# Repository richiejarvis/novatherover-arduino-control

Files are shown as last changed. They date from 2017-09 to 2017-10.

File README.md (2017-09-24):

# novatherover-arduino-control
Arduino Control code for Nova the Rover

*Richie Jarvis - http://nebul.ae*
*2017-09-24 - GPL licenced*

## Introduction
Nova the Rover (https://www.facebook.com/novatherover) is an Arduino controlled project I started a couple of years ago with a simple 24v Mobility Scooter brought off Ebay.  

## 2016 - Initial Chassis Building

I started off by rebuilding the chassis.  In hindsight I made more work for myself, but did learn to weld of-sorts.  In the first year of operation the contraption was a powered pull-cart/human carrying workhorse.  The steering was backwards at her first public outing, which made control interesting.  She was present at Lewes Bonfire Celebrations in 2016 lurking with the Bonfire Boyes, and got covered in red paper from firecrackers.

It was always my hope to convert the chassis into a remotely steerable unit, so I purchased a Lynxmotion PS2 controller (http://www.robotshop.com/uk/lynxmotion-ps2-controller-v4.html) and a cheap 12v 30mm/s Linear Actuator from Ebay (http://www.ebay.co.uk/itm/222620724976).

## 2017 - Conversion to Remote Control via PS2 Controller

Originally I was hoping to use the original computer/controller unit that came with the Mobility scooter.  Unfortunately, that was not as easy as I first hoped, so I ditched that idea and purchased a 30A Cytron DC Motor Driver (http://www.robotshop.com/en/cytron-30a-5-30v-single-brushed-dc-motor-driver.html) to control the motors.

I then added an Arduino Uno (http://www.robotshop.com/uk/arduino-uno-r3-usb-microcontroller.html) and a 4 relay board to handle the switching of polarity, turning the magnetic brake on/off, etc to finish things off.

This project is the current set of control code as it develops over time.

##Thinking Ahead

Thoughts/Plans so far:
1. Replace on/off relay control on Linear Actuator with a proper ESC to give more granular steering.
2. Add navigation lights, (loud) horn and control indicator LED to signal status
3. Add Distance sensor(s)
4. Add magnetic detector
5. Add camera
6. Add Raspberry Pi + intelligence(!?)
7. Add weaponry :)

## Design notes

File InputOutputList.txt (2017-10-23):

Battery1+/24vPositive/12vPositive
Battery1-/12vGround
Battery2+
Battery2-/24vGround
24vBrake
24vBrake
24vMotor
24vMotor

12vSteering
12vSteering
24vGround
24vLights1
24vLights2
24vLights3
12vGround
12vMischief1
12vMischief2
12vMischief3
12vMischief4
12vMischief5

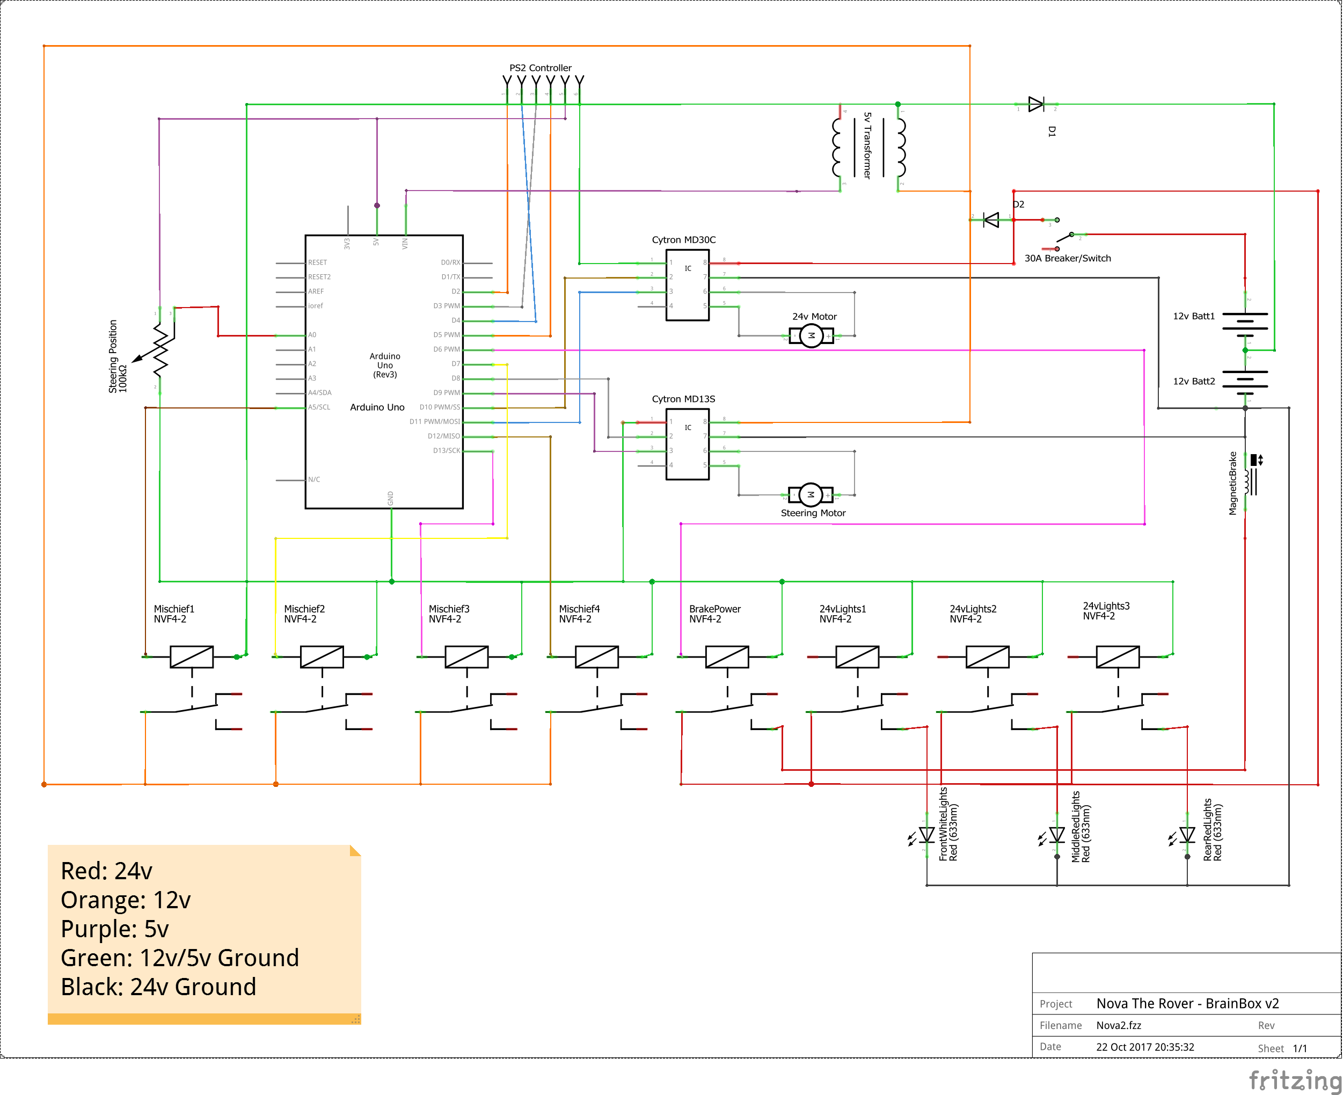
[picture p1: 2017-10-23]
Nova2_schem.png

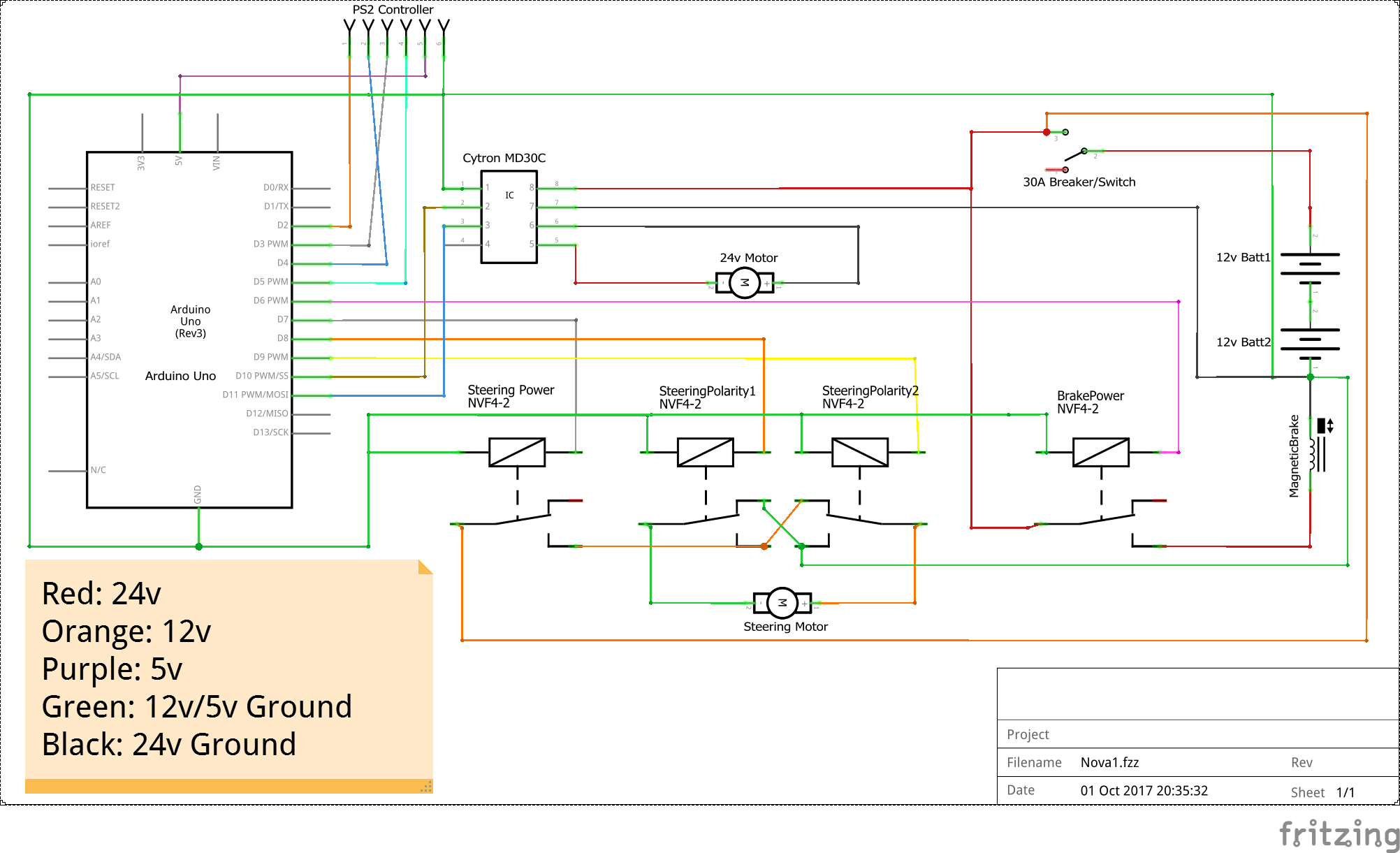
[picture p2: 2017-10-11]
Nova1_schem.png

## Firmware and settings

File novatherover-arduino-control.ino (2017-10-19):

#include <PS2X_lib.h>

// PS2 Controller pins
#define PS2_DAT        2
#define PS2_CMD        4
#define PS2_ATT        3
#define PS2_CLK        5

// Magnetic Brake
#define RELAY1_PIN     6

// Steering Power
#define RELAY2_PIN     7

// Steering Relay pins
#define RELAY3_PIN     8
#define RELAY4_PIN     9

// Motor direction pin
#define DIR_PIN        10

// Throttle pin
#define PWM_PIN        11

#define PS2_PRESSURES  false
#define PS2_RUMBLE     false

PS2X ps2x; // create PS2 Controller Class

// Initial Startup Variables
int error = 0;
byte type = 0;
byte vibrate = 0;
int pwm_value = 0;
int throttle_pos = 127;
int steering_pos = 127;

int max_speed = 20;
int counter = 0;
int buttonBounceCounter = 0;

// Set pin vars to off/high
int motor_direction = HIGH;
int brake_power = true;
int steering_power = HIGH;
int steering_relay_1 = HIGH;
int steering_relay_2 = HIGH;
int increment = 0;
int target_speed = 0;
int pss_lx = 0;
int pss_ly = 0;
int pss_rx = 0;
int pss_ry = 0;
int lights_counter = 0;
int light_delay = 40;

boolean cruise_control = false;
boolean beast_mode = false;
boolean first_run = false;
boolean skip_initial = true;
boolean controller_present = false;
boolean accept_change = true;


// Storage array to record previous condition
int storage_array[20];

// Card reset function
void(* resetFunc) (void) = 0;


void flashLights(int max_count) {
  // Flash Lights to indicate readyness
  for (int count = 0 ; count < max_count  ; count++) {
    digitalWrite(RELAY1_PIN, brake_power);
    delay(light_delay);
    digitalWrite(RELAY1_PIN, !brake_power);
    delay(light_delay);
  }
  digitalWrite(RELAY1_PIN, brake_power);
}


void setup()
{
  Serial.begin(57600);
  delay(300);
  // GamePad(clock, command, attention, data, Pressures?, Rumble?) check for error
  error = ps2x.config_gamepad(PS2_CLK, PS2_CMD, PS2_ATT, PS2_DAT, PS2_PRESSURES, PS2_RUMBLE);

  if (error == 1)
    Serial.println("No controller found, check wiring, see readme.txt to enable debug. visit www.billporter.info for troubleshooting tips");

  else if (error == 2)
    Serial.println("Controller found but not accepting commands. see readme.txt to enable debug. Visit www.billporter.info for troubleshooting tips");

  else if (error == 3)
    Serial.println("Controller refusing to enter Pressures mode, may not support it. ");

  // Something up with the controller - abort and reboot!
  // Delay in place to stop it checking too frequently....
  if (error != 0) {
    Serial.println("Init Restart");
    delay(2000);
    resetFunc();
  } else {
    Serial.println("Startup Successful");
    controller_present = true;
  }

  // Set pin 11 PWM frequency to 62500 Hz (62500/1 = 62500)
  TCCR2B = TCCR2B & 0b11111000 | 0x01;

  //Initialise outputs
  pinMode(PWM_PIN, OUTPUT);
  pinMode(DIR_PIN, OUTPUT);
  pinMode(RELAY1_PIN, OUTPUT);
  pinMode(RELAY2_PIN, OUTPUT);
  pinMode(RELAY3_PIN, OUTPUT);
  pinMode(RELAY4_PIN, OUTPUT);
  // Set initial states
  digitalWrite(RELAY1_PIN, brake_power);
  digitalWrite(RELAY2_PIN, steering_power);
  digitalWrite(RELAY3_PIN, steering_relay_1);
  digitalWrite(RELAY4_PIN, steering_relay_2);


}

// Controls
// PSAB_L1 - Max Speed Down
// PSAB_R1 - Max Speed Up
// PSAB_CIRCLE - Cruise On/Off
// PSS_LY/PSS_RY - Left Stick (Up/Down) - Throttle
// PSS_LX/PSS_RX - Right Stick (Left/Right) - Steering
// PSB_TRIANGLE - Speed 20 (Lowest working speed)
// PSB_SQUARE - Emergency Stop

void speedChange() {
  first_run = true;
  Serial.print("SC");
  // Check for beast_mode first....
  if (!beast_mode) {
    if ((target_speed != pwm_value)) {
      // Speed up more gently

      if (first_run) {
        // Only set the increment once
        increment = target_speed / 50;
        if (increment < 1) {
          increment = 1;
        }
        first_run = false;
      }
      if (target_speed > pwm_value) {
        pwm_value = pwm_value + increment;
        if (pwm_value > target_speed) {
          pwm_value = target_speed;
        }
      }
      else if (target_speed < pwm_value) {
        // Slow down in a less jolty-way
        if (pwm_value > 0 && pwm_value < 100) {
          // speed is less than 50 - use 10 step slowdown
          pwm_value = pwm_value - 2;
        } else if (pwm_value >= 100 & pwm_value < 200) {
          // speed is greater than 100 && less than 200 - use 30 step slowdown
          pwm_value = pwm_value - 5;
        } else if (pwm_value >= 200) {
          // speed is greater than 200 use 60 step slowdown
          pwm_value = pwm_value - 10;
        }
      }

    }
  } else if (pwm_value != target_speed) {
    pwm_value = target_speed - 10;
  } else if (pwm_value == target_speed - 10){
    pwm_value = target_speed;
  }

  // Make sure values are between 0 and 255
  if (pwm_value < 0) {
    pwm_value = 0;
  }
  if (pwm_value > 255) {
    pwm_value = 255;
  }
}

// Write current values to the EEPROM for permanent storage for later retrieval.
// Might not need to store too much....
boolean dumpToEeprom() {
  //
}

// Make numbers appear in
String threeDigitFormat(int value) {
  if (value < 10) {
    return "00" + String(value);
  } else if (value < 100) {
    return "0" + String(value);
  } else {
    return String(value);
  }
}


void loop()
{
  ps2x.read_gamepad();
  // If there is no controller connected on startup, the init part seems to report working
  // Then we get strange values set in the pwm and speed fields
  // Workaround to skip the first loop on restart of Arduino
  if (!skip_initial) {
    pss_lx = ps2x.Analog(PSS_LX);
    pss_ly = ps2x.Analog(PSS_LY);
    pss_rx = ps2x.Analog(PSS_RX);
    pss_ry = ps2x.Analog(PSS_RY);
    // Check the stick positions.
    // If they are all at 0,128 or 0, then there is a controller problem, and we should not do anything
    if (pss_lx == 128 && pss_ly == 128 && pss_rx == 128 && pss_ry == 128
        || (pss_lx == 255 && pss_ly == 255 && pss_rx == 255 && pss_ry == 255)
       ) {
      controller_present = false;
    } else {
      controller_present = true;
      // Read the Y position (Throttle)
      // 0-126 == Up
      // 127 == At rest
      // 128 == disconnected
      // 129-255 == Down
      // Read the Left stick position in preference to Right
      // RX and LX report 128 in middle position
      // If LX is reporting something, then use that
      // Otherwise use RX
      throttle_pos = pss_ly;
      if ((throttle_pos == 127 || throttle_pos == 128)) {
        throttle_pos = pss_ry;
      }
      // Read the X position (Steering)
      // 0-126 == Left
      // 127 == At rest
      // 128 == disconnected
      // 129-255 == Right

      // Read the Left stick position in preference to Right
      // If LX is reporting something, then use that
      // Otherwise use RX
      steering_pos = pss_lx;
      if (steering_pos == 127 || steering_pos == 128) {
        steering_pos = pss_rx;
      }


      // Set the Throttle Position.
      // Ignore if Cruise is on.
      if (!cruise_control) {
        if (throttle_pos < 90) {
          // Go Forward
          target_speed = map(throttle_pos, 128, 0, 0, max_speed);
          motor_direction = LOW;
        } else if (throttle_pos > 190) {
          // Go Backwards
          target_speed = map(throttle_pos, 128, 255, 0, max_speed);
          motor_direction = HIGH;
        } else if (throttle_pos == 127 ) {
          target_speed = 0;
        }
      } else {
        target_speed = max_speed;
      }

      // Adjust the steering via relays
      if (steering_pos < 125 ) {
        // Steer Left
        steering_power = LOW;
        steering_relay_1 = LOW;
        steering_relay_2 = LOW;

      } else if (steering_pos > 130) {
        // Steer Right
        steering_power = LOW;
        steering_relay_1 = HIGH;
        steering_relay_2 = HIGH;

      } else  {
        // Don't Move
        steering_power = HIGH;
        // These 2 aren't needed, except to turn the Relay LED's off.....
        steering_relay_1 = HIGH;
        steering_relay_2 = HIGH;
      }
      // Modify Max Speed
      if (ps2x.Button(PSB_L1)) {
        max_speed = max_speed - 2;
        first_run = true;
      }
      if (ps2x.Button(PSB_R1)) {
        max_speed = max_speed + 2;
        first_run = true;
      }
      // Emergency Stop
      if (ps2x.Button(PSB_CROSS)) {
        pwm_value = 0;
        brake_power = HIGH;
        target_speed = 0;
        cruise_control = false;
        flashLights(1);
      }
      if (accept_change) {
        // Beast Mode
        // If disabled, turn it on
        // If enabled, turn it off
        if (!beast_mode) {
          // Enable Beast Mode
          if (ps2x.Button(PSB_SELECT)) {
            beast_mode = true;
            max_speed = 255;
            //            target_speed = 255;
            //            pwm_value = 230;
            accept_change = false;
            flashLights(5);
          }
        } else {
          // Disable Beast Mode
          if (ps2x.Button(PSB_SELECT)) {
            beast_mode = false;
            max_speed = 20;
            target_speed = 20;
            accept_change = false;
            flashLights(3);
          }
        }
        // Cruise Control
        // If disabled, turn it on
        // If enabled, turn it off
        if (!cruise_control) {
          if ((ps2x.Button(PSB_R2) || ps2x.Button(PSB_L2))) {
            cruise_control = true;
            pwm_value = target_speed;
            accept_change = false;
            flashLights(6);
          }
        } else {
          // Cruise Off
          if ((ps2x.Button(PSB_R2) || ps2x.Button(PSB_L2))) {
            cruise_control = false;
            target_speed = 0;
            first_run = true;
            accept_change = false;
            flashLights(4);

          }
        }
      }
      // Reset accept_change if buttons are not pushed
      if (!(ps2x.Button(PSB_SELECT) || ps2x.Button(PSB_R2) || ps2x.Button(PSB_L2))) {
        accept_change = true;
      }
    }


    // Limit max speed
    if (max_speed > 255) {
      max_speed = 255;
    }
    if (max_speed < 15) {
      max_speed = 15;
    }



    if (pwm_value == 0 ) {
      lights_counter++;
      if (lights_counter > 100 ) {
        brake_power = HIGH;
        lights_counter = 100;
      }
    }
    else if (pwm_value > 0) {
      brake_power = LOW;
      lights_counter = 0;
    }
    if (controller_present) {
      // Store values to see if they are consistent
      // Use case:
      // Only activate/deactivate cruise control when button is released
      // To stop on/off/on/off scenario whilst button is down
      storage_array[0] = max_speed;
      storage_array[1] = pwm_value;
      storage_array[2] = target_speed;
      storage_array[3] = motor_direction;
      storage_array[4] = cruise_control;
      storage_array[5] = beast_mode;
      storage_array[6] = brake_power;
      storage_array[7] = steering_power;
      storage_array[8] = steering_pos;
      storage_array[9] = throttle_pos;
      storage_array[10] = steering_relay_1;
      storage_array[11] = steering_relay_2;
      if (pwm_value != target_speed) {
        speedChange();
      }

      // Do Stuff!
      // Turn brake/lights off
      digitalWrite(RELAY1_PIN, brake_power);

      digitalWrite(DIR_PIN, motor_direction);
      // Setup steering
      digitalWrite(RELAY3_PIN, steering_relay_1);
      digitalWrite(RELAY4_PIN, steering_relay_2);
      // Now turn the power on for the steering
      digitalWrite(RELAY2_PIN, steering_power);
      // Set the throttle
      analogWrite(PWM_PIN, pwm_value);
    } else {
      target_speed = 0;
    }
  } else {
    // First loop over - go to normal mode
    skip_initial = false;
  }
  // *********************
  // Output Current Status
  // *********************
  Serial.print("LX:" + threeDigitFormat(pss_lx));
  Serial.print(" LY:" + threeDigitFormat(pss_ly));
  Serial.print(" RX:" + threeDigitFormat(pss_rx));
  Serial.print(" RY:" + threeDigitFormat(pss_ry));
  Serial.print(" max_spd:" + threeDigitFormat(max_speed));
  Serial.print(" pwm:" + threeDigitFormat(pwm_value));
  Serial.print(" trgt_spd:" + threeDigitFormat(target_speed));
  Serial.print(" fwd:" + String(motor_direction) );
  Serial.print(" cruise:" + String(cruise_control));
  Serial.print(" beast:" + String(beast_mode));
  Serial.print(" stop:" + String(brake_power));
  Serial.print(" spd:" + threeDigitFormat(throttle_pos));
  Serial.print(" dir:" + threeDigitFormat(steering_pos));
  Serial.print(" pad:" + String(controller_present));
  Serial.println(" dir:" + String(steering_power) + String(steering_relay_1) + String(steering_relay_2));
  delay (20);
}

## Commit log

2017-09-24 Added link to Arduino-PS2X repo from Bill Porter)
2017-09-26 Todays version - mostly works - beast mode screwed ;)
2017-10-06 Cruise control and beast mode broken
    [novatherover-arduino-control.ino]
2017-10-06 Added schematic
    [Nova1.fzz]
2017-10-11 Updated schematic and added light-on initial try
    [Nova1.fzz]
2017-10-11 Updated schematic png
2017-10-19 Brake fixed!
2017-10-23 BrainBox v2 pretty much done
    [Nova1.fzz, Nova2.fzz]
2017-10-23 BrainBox v2 pretty much done (update()
    [Nova2.fzz]
